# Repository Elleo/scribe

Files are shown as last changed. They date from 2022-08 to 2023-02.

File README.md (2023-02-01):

<p align="center">
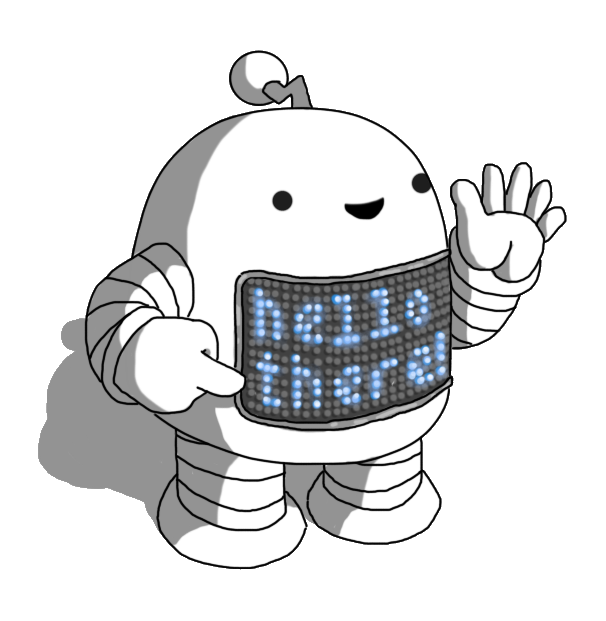
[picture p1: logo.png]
A small robot for captioning your performances


# Scribe
Scribe is a device for automatically captioning live performances. Both the hardware and software are open source.

# Hardware
The device can be built for approximately £170, making it suitable for small theatres and individual artists on limited budgets.

## Components
 * [Raspberry Pi 4 (or later) with at least 2GB of RAM](https://thepihut.com/products/raspberry-pi-4-model-b?variant=20064052674622) - £52
 * [SD card](https://thepihut.com/products/noobs-preinstalled-sd-card) - £9
 * [Ada-Fruit 32x64 RGB Matrix](https://thepihut.com/products/adafruit-64x32-rgb-led-matrix-4mm-pitch) - £39.80
   - These are available in different element spacing sizes (pitch). Smaller pitch sizes are more appropriate for viewing at close range, while higher pitch values are better viewed at a distance. A 4mm pitch gives a good middle ground for most venues. Currently only the 4mm pitch size has a case designed.
 * [Ada-Fruit RGB Matrix Driver Bonnet](https://thepihut.com/products/adafruit-rgb-matrix-bonnet-for-raspberry-pi-ada3211) - £14.70
 * [Power supply](https://thepihut.com/products/neopixel-power-brick-5v-5a-25w) - £23
   - [C7 lead](https://thepihut.com/products/figure-8-type-power-cable-2m-c7-uk) (if not included with power supply) - £3
 * [USB audio capture device](https://thepihut.com/products/mini-usb-microphone) - £5.20
 * [M3 x 12mm screws or hex screws](https://www.amazon.co.uk/12mm-Socket-Screw-Bolt-Head/dp/B084RFHZ2F) x 11 - £5.39 (pack of 20)
 * [M3 brass inserts](https://www.amazon.co.uk/sourcing-map-Knurled-Insert-Embedding/dp/B09MCWTGLZ) x 6 - £7.49 (pack of 50)
 * [DC extension cable](https://www.amazon.co.uk/dp/B0792HD7CC) - £4.99
 * [Mic stand adaptors](https://www.amazon.co.uk/dp/B08JPS4LNN?psc=1&ref=ppx_yo2ov_dt_b_product_details) - £6.95
   
  (You might be able to get screws and brass inserts cheaper by buying them individually from a local hardware store)
   
  All prices are including VAT, and were last updated in January 2023. Total cost: £171.52

## Case
 *NOTE: The case design is still being prototyped, the current iteration has a number of issues that are being worked on, so it's recommended that you don't print a case for now.*

 The case can be 3D printed using the STL files in [/case/stl](/case/stl). Select the appropriate case size based on your RGB matrix size and pitch. For each case size there is an STL for the complete case in one piece or if your print bed is not large enough to fit the whole case in one piece there is a version split into two parts.

# Software
The scribe software allows for multiple shows to be configured with individual settings. Performers can upload scripts to the device to guide the speech recognition system and provide for greatly increased accuracy. All speech recognition is done on the device itself and does not require any internet connection during perfomances.

# Contributors

<!-- ALL-CONTRIBUTORS-LIST:START - Do not remove or modify this section -->
<!-- prettier-ignore-start -->
<!-- markdownlint-disable -->

<table>
  <tbody>
    <tr>
      <td align="center" valign="top" width="14.28%"><a href="https://github.com/Elleo">Mike Sheldon<br /><sub><b>Mike Sheldon</b></sub></a><br /><a href="https://github.com/Elleo/scribe/commits?author=Elleo" title="Code">💻</a> <a href="#ideas-Elleo" title="Ideas, Planning, & Feedback">🤔</a> <a href="#infra-Elleo" title="Infrastructure (Hosting, Build-Tools, etc)">🚇</a> <a href="#maintenance-Elleo" title="Maintenance">🚧</a> <a href="#projectManagement-Elleo" title="Project Management">📆</a> <a href="#financial-Elleo" title="Financial">💵</a></td>
    </tr>
  </tbody>
</table>

<!-- markdownlint-restore -->
<!-- prettier-ignore-end -->

<!-- ALL-CONTRIBUTORS-LIST:END -->

This project follows the [all-contributors](https://github.com/all-contributors/all-contributors) specification. Contributions of any kind welcome!

## Logo
The logo was kindly designed by [Thomas Heasman-Hunt](https://twitter.com/smolrobots)

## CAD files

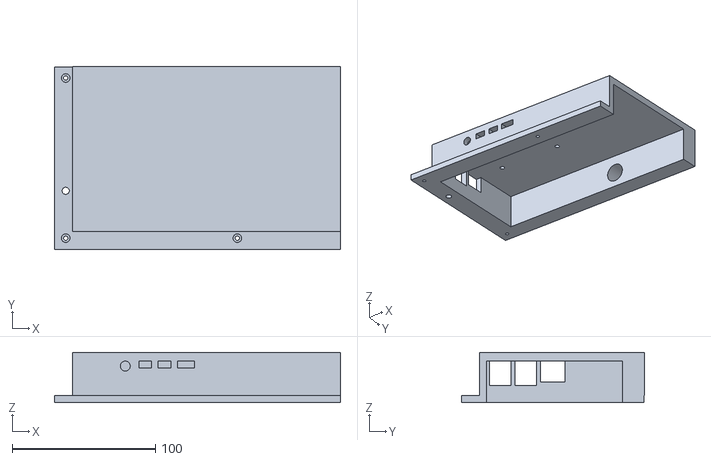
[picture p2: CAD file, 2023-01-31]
case/stl/64x32 - 4mm pitch - Part 1.stl
200.0 x 127.8 x 35.0

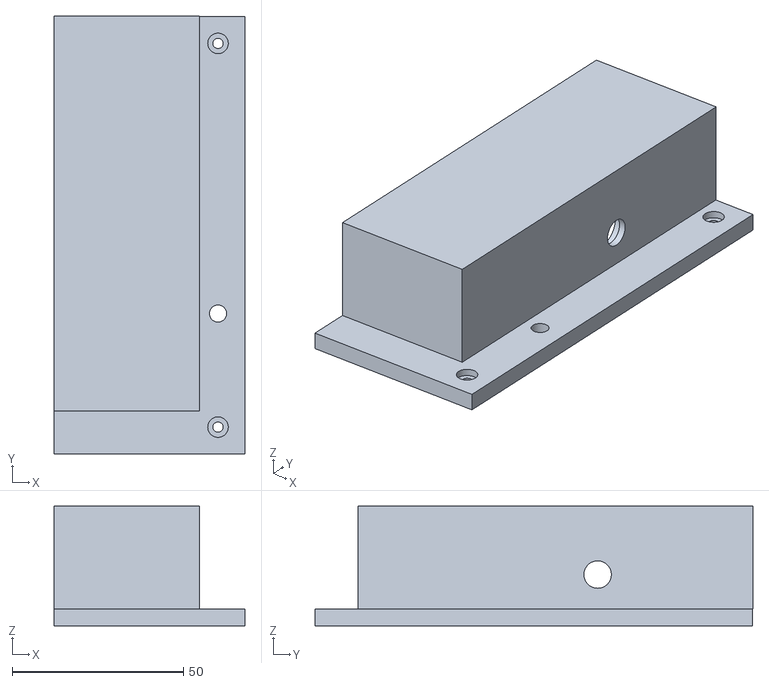
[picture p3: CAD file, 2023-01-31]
case/stl/64x32 - 4mm pitch - Part 2.stl
55.7 x 127.8 x 35.0

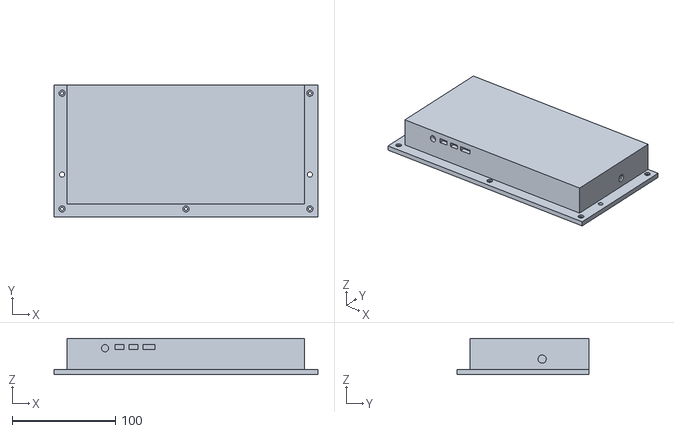
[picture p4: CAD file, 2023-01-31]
case/stl/64x32 - 4mm pitch.stl
255.7 x 127.8 x 35.0

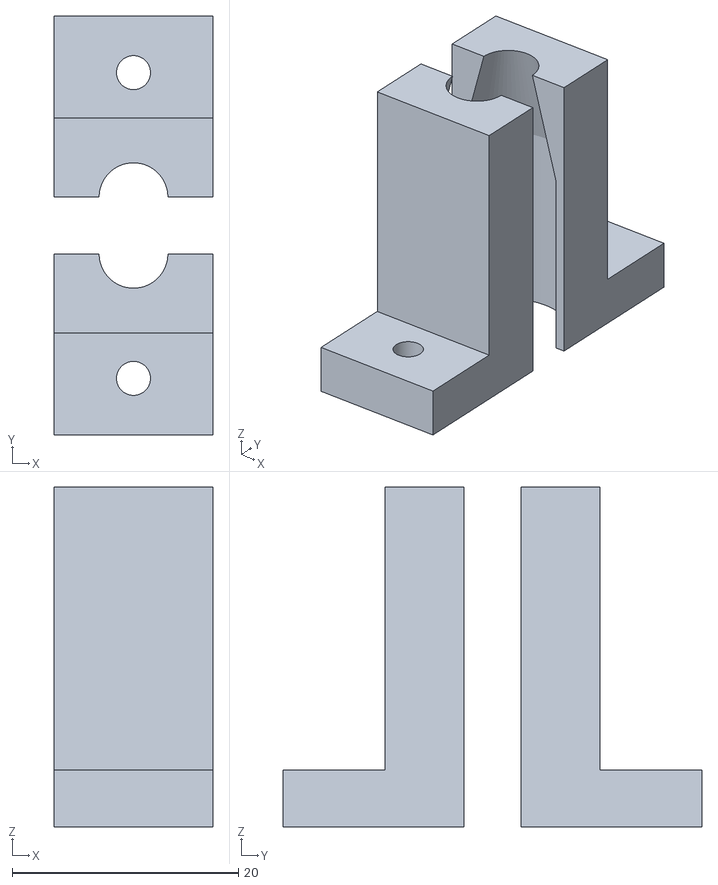
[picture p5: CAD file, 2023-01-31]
case/stl/DC bracket.stl
14.0 x 37.0 x 30.0

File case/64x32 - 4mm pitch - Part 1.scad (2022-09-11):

use <64x32 - 4mm pitch.scad>

module cut() {
    translate([200, -1, -1])
    cube([60, 130, 60]);
}

difference() {
    case();
    cut();
}

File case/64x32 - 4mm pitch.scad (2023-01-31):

// Base plate
module case() {
    difference() {
        difference() {
            cube([255.70, 127.70, 5]);
            translate([17.5, 17.5, -1])
            cube([220, 95, 7]);
        }
        // Screw holes
        translate([7.85, 7.85, -1])
        cylinder(7, d=3, $fn=64);
        translate([7.85, 7.85, 3])
        cylinder(3, d=6, $fn=64);
        translate([7.85, 119.85, -1])
        cylinder(7, d=3, $fn=64);
        translate([7.85, 119.85, 3])
        cylinder(3, d=6, $fn=64);
        translate([127.85, 7.85, -1])
        cylinder(7, d=3, $fn=64);
        translate([127.85, 7.85, 3])
        cylinder(3, d=6, $fn=64);
        translate([247.85, 119.85, -1])
        cylinder(7, d=3, $fn=64);
        translate([247.85, 119.85, 3])
        cylinder(3, d=6, $fn=64);
        translate([247.85, 7.85, -1])
        cylinder(7, d=3, $fn=64);
        translate([247.85, 7.85, 3])
        cylinder(3, d=6, $fn=64);

        // Holes for plastic prongs
        translate([7.85, 41, -1])
        cylinder(7, d=5, $fn=64);
        translate([247.85, 41, -1])
        cylinder(7, d=5, $fn=64);
    }

    // Box
    translate([12.5, 12.5, 5])
    difference() {
        difference() {
            cube([230, 115.35, 30]);
            translate([5, 5, -1])
            cube([220, 95, 25]);
        }

        // Mic stand screw hole
        translate([115, 116, 8])
        rotate([90, 0, 0])
        // Hole should be slightly too small, so thread can be melted in
        cylinder(16.1, d=15.5, $fn=64);

        // Raspberry Pi mounting holes
        translate([86.9, 57.9, 23])
        cylinder(5, d=4, $fn=64);
        translate([86.9, 8.9, 23])
        cylinder(5, d=4, $fn=64);
        translate([28.9, 57.9, 23])
        cylinder(5, d=4, $fn=64);
        translate([28.9, 8.9, 23])
        cylinder(5, d=4, $fn=64);

        // Raspberry Pi ports
        translate([-1, 7, 7])
        cube([7, 15, 17]);
        translate([-1, 25, 7])
        cube([7, 15, 17]);
        translate([-1, 42.8, 9.5])
        cube([7, 17, 14.5]);
        rotate([90, 0, 0])
        translate([37, 20.5, -6])
        cylinder(7, d=7, $fn=64);
        translate([46.5, -1, 19.3])
        cube([9, 7, 4.7]);
        translate([60, -1, 19.3])
        cube([9, 7, 4.7]);
        translate([73.5, -1, 19.3])
        cube([12, 7, 4.7]);

        // DC socket hole
        rotate([0, 90, 0])
        translate([-10, 70, 224])
        cylinder(7, d=8, $fn=64);
        rotate([0, 90, 0])
        translate([-10, 70, 224])
        cylinder(4, d=12, $fn=64);

        // DC bracket screw holes
        rotate([0, 90, 0])
        translate([-8, 81, 224])
        cylinder(5, d=3, $fn=64);
        rotate([0, 90, 0])
        translate([-8, 60, 224])
        cylinder(5, d=3, $fn=64);
    }

}

case();

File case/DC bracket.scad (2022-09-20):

module bracket() {
    difference() {
        cube([14, 9, 5]);
        translate([7, 5, -1])
        cylinder(7, d=3, $fn=64);
    }
    translate([0, 22, 0])
    difference() {
        cube([14, 10, 5]);
        translate([7, 5, -1])
        cylinder(7, d=3, $fn=64);
    }
    translate([0, 9, 0])
    difference() {
        cube([14, 14, 30]);
        translate([7, 7, -1])
        cylinder(20, d=12, $fn=64);
        translate([7, 7, 18.99])
        cylinder(13, d1=12, d2=5, $fn=64);
    }
}

module cut() {
    translate([-1, -1, -1])
    cube([16, 17, 40]);
}

translate([0, 5, 0])
difference() {    
    bracket();
    cut();
}

intersection() {    
    bracket();
    cut();
}

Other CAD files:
case/64x32 - 4mm pitch - Part 2.scad

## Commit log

2022-08-21 Switch to sidebar
2022-08-23 Begin designing case
    [64x32 - 4mm pitch.scad]
2022-09-05 Make it possible to screw the case on to the display
    [64x32 - 4mm pitch.scad]
2022-09-05 Add screw hole for microphone stand
    [64x32 - 4mm pitch.scad]
2022-09-05 Avoid roof of box with microphone hole
    [64x32 - 4mm pitch.scad]
2022-09-05 Add centre screw hole to case
    [64x32 - 4mm pitch.scad]
2022-09-11 Cut case into two parts to fit print bed
    [64x32 - 4mm pitch.scad]
2022-09-11 Separate split case into individual files
    [64x32 - 4mm pitch - Part 1.scad, 64x32 - 4mm pitch - Part 2.scad, 64x32 - 4mm pitch.scad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]
2022-09-11 Add script for generating STLs
    [64x32 - 4mm pitch.stl]
2022-09-11 Add pre-generated STLs
    [64x32 - 4mm pitch - Part 1.stl, 64x32 - 4mm pitch - Part 2.stl, 64x32 - 4mm pitch.stl]
2022-09-11 Add basic case printing instructions
2022-09-12 Update screw hole sizing
    [64x32 - 4mm pitch - Part 1.stl, 64x32 - 4mm pitch - Part 2.stl, 64x32 - 4mm pitch.scad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]
2022-09-12 Fix hole dimensions, slim down case size
    [64x32 - 4mm pitch.scad]
2022-09-12 Update STLs
    [64x32 - 4mm pitch - Part 1.stl, 64x32 - 4mm pitch - Part 2.stl, 64x32 - 4mm pitch.stl]
2022-09-12 Add Raspberry Pi mounting holes and smooth other screw holes
    [64x32 - 4mm pitch.scad]
2022-09-12 Enlarge mounting holes to account for brass inserts, leave material to cover top of them
    [64x32 - 4mm pitch.scad]
2022-09-12 Add USB and ethernet port holes
    [64x32 - 4mm pitch.scad]
2022-09-12 Add Raspberry PI ports
    [64x32 - 4mm pitch.scad]
2022-09-13 Add quantities of screws and brass inserts
2022-09-13 Add holes for plastic prongs on matrix display
    [64x32 - 4mm pitch.scad]
2022-09-16 Add hole for DC socket
    [64x32 - 4mm pitch.scad]
2022-09-16 Add screw holes for mounting DC bracket
    [64x32 - 4mm pitch.scad]
2022-09-18 Adjust DC bracket hole positions
    [64x32 - 4mm pitch.scad]
2022-09-18 Add DC bracket
    [DC bracket.scad]
2022-09-19 Make DC bracket larger
    [DC bracket.scad]
2022-09-19 Tweak prong positioning, add slack
    [64x32 - 4mm pitch.scad]
2022-09-19 Increase DC hole size
    [64x32 - 4mm pitch.scad]
2022-09-20 Fix DC bracket edge
    [DC bracket.scad]
2022-11-19 Update case design
    [64x32 - 4mm pitch - Part 1.stl, 64x32 - 4mm pitch - Part 2.stl, 64x32 - 4mm pitch.stl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]
2023-01-29 Add display of available wifi networks and current network
2023-01-30 Add support for switching scripts in scriberecognition
2023-01-30 Display currently active show
2023-01-30 Tweak mic screw thread sizing
    [64x32 - 4mm pitch - Part 1.stl, 64x32 - 4mm pitch - Part 2.stl, 64x32 - 4mm pitch.scad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]
2023-01-31 Tweak positioning of hole for plastic prong
    [64x32 - 4mm pitch - Part 1.stl, 64x32 - 4mm pitch - Part 2.stl, 64x32 - 4mm pitch.scad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]
2023-01-31 Add mic stand adaptors to bill of materials
2023-02-01 Add note to case instructions
